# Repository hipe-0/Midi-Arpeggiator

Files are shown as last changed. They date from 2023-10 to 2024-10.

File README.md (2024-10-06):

# Midi-Arpeggiator: A Creative Tool for Musicians of All Levels

Hi, I'm Hippolyte Mounier, and I'm learning Arduino and electronics. This fun project has been a great way to unlock my musical creativity. The Midi-Arpeggiator serves as both an arpeggiator and a composition tool, helping me quickly express ideas even though I'm not a professional composer or pianist. Designed for use with DAW software like Ableton Live, FL Studio, and Reason, this plug-and-play device connects via USB to your desktop, offering a seamless experience. Check out the demo and see how this little Arduino project turned out more professional and robust than I ever expected—after just one week of development!

Demo here on Youtube https://www.youtube.com/watch?v=DeB5YvRfC6c

Photo of the Full Assembly:

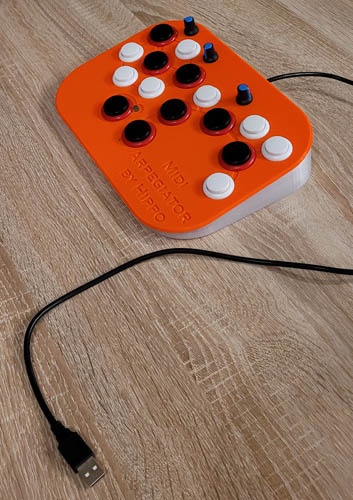
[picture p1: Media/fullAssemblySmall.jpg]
full assembly


Full schematic of the main panel: May look complex at first :-) but it's fool proof. My 10 years old daughter can play it! In theory you should use the big buttons more often than the small ones.

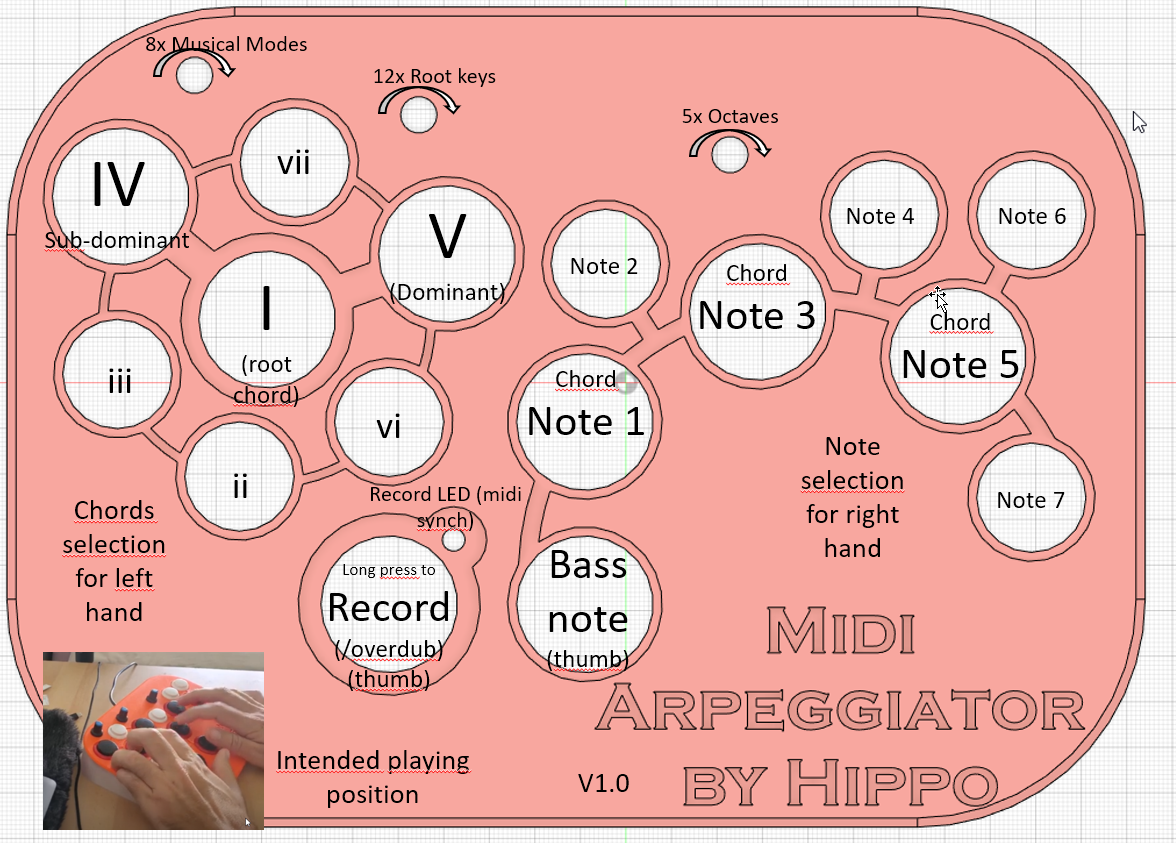
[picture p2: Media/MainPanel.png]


# Features 
+ USB midi controler
+ Original design
+ No reference to existing devices
+ Inspiration from software midi VST like Instachord, Melodicflow, Nora, Chtullu or Captain Chord.
+ 3D Made with Fusion 360. (files on thingiverse, see link below)
+ The body is 3D printed in PETG plastic, in 2 pieces : orange face (6h printing time) and translucent walls (3h printing time) glued together. A plug on the back secures the usb cable. (30 min printing time, in 2 parts)
+ Arcade machine buttons

# Usage tricks
7 buttons on left hand are presets for the chords I, II, III, IV, V, VI and VII of the mode and the root key (choosen via potentiometer below)
+  Pressing a chord button twice inverts the chord (minor gets major and major gets minor)
+  Pressing a chord 3 times pushes all notes +1 semitone, to reach out-of-harmony chords and accidentals

8 buttons for individual notes 1-7 in a key, similar to a piano white keys for C major
  + Inclusive a bass note for the right thumb, 1 octave down

A single record button. Performing :
  1. record (press continuously, it plays a loop immediately after button release), 
  2. play (short press), 
  3. overdub (press continuously while playing) 
  4. and stop (short press) 

# Potentiometer action

3x potentiometers for (8x)Mode, (12x)Root Keys and (5x)Octave

8x Music modes I choose are 
  1. Major
  2. Minor harmonic
  3. Minor melodic
  4. Minor natural (eolian)
  5. Dorian (celtic)
  6. Mixolydian (folk blues)
  7. Phrygian (metal)
  8. Phrygian Dominant (metal)

12x Root Keys I choose are 
+ in order of fiths starting with C, then G, D, A, E, B, F#, ...
+ Goal: being in fifths you can apply most useful tonal changes easily    

5x Octaves I choose are 
    -2, -1, 0, +1, +2

+ Recording led : green
+ The "brain" of the system is an Arduino micro, using midiusb library
+ Coding in C++ by me
+ I used a prototype board and soldered only some basic resistors and the wires.
+ Midi synchronisation as slave. 
+ Midi Velocity is fixed value (100) only
+ Midi Chanel 1 only
+ Latency is in my opinion negligible. At least on my Focusrite scarlett solo ASIO sound card. Some Latency can be seen on midi note editor.

It took me roughly about 12 h to build the prototype from start to finish. (I'm learning !)

# Shematic

2024-09-23 sketch Arpegiator v1 01_bb

2024-09-23 sketch Arpegiator v1 01_schéma

Arduino pins:
+ pin A0 connects to mode pot
+ pin A1 connects to Root pot
+ pin A2 connects to octave pot
+ pin A3 connects to chord buttons voltage read with Resistors in parallel for each button to differentiate voltages + 1 single 1K resitor in serie + 1 x 0.22uF capacitor in parallel for smooting the values, optional
+  button for chord I is connected directly with no resistor
+  button for chord II is in serie with 100 Ohm resistor
+  button for chord III is in serie with 320 Ohm resistor
+  button for chord IV is in serie with 560 Ohm resistor
+  button for chord V is in serie with 1K Ohm resistor
+  button for chord VI is in serie with 2.2K Ohm resistor
+  button for chord VII is in serie with 10K Ohm resistor

All note buttons are connected to GND

all pots connected to pin AREF and GND
+ pin 2 is connected to button note 1 
+ pin 3 is connected to button note 2
+ pin 4 is connected to button note 3
+ pin 5 is connected to button note 4
+ pin 6 is connected to button note 5
+ pin 7 is connected to button note 6
+ pin 8 is connected to button note 7
+ pin 10 is connected to LED in serie with resistor (probably 1K)
+ pin 11 is connected to button "bass" note
+ pin 12 in connected to record button

Dimensions: roughly 250 x 185 x 65

# Bill of materials:
+ Arduino Micro
+ 1m USB cable that connects USB A to USB micro
+ 8 large arcade buttons
+ 8 small arcade buttons
+ wire
+ 0.22 uF capacitor
+ 6x resistors R = 100, 320, 560, 1K, 2.2K and 10K
+ 1x resistor for the led R= 1K
+ PETG filament for 3D printer (PLA should do fine too)
+ 3D printer with heated bed and large >=250 cm print area
+ super glue, to bond the plate and the side wall
+ prototype board 70x90
+ 2x M3 screws
+ 3 potentiometers 10K
+ soldering iron

# Reddit thread

https://www.reddit.com/r/ArduinoProjects/comments/171mva3/new_arduino_based_midi_arpeggiator_3d_printed/

# 3D models

https://www.thingiverse.com/thing:6257589

# License:
CC BY-NC, see https://creativecommons.org/licenses/by-nc/4.0/
This license enables reusers to distribute, remix, adapt, and build upon the material in any medium or format for noncommercial purposes only, and only so long as attribution is given to the creator. CC BY-NC includes the following elements:

 BY: credit must be given to the creator.
 NC: Only noncommercial uses of the work are permitted.

Hippolyte

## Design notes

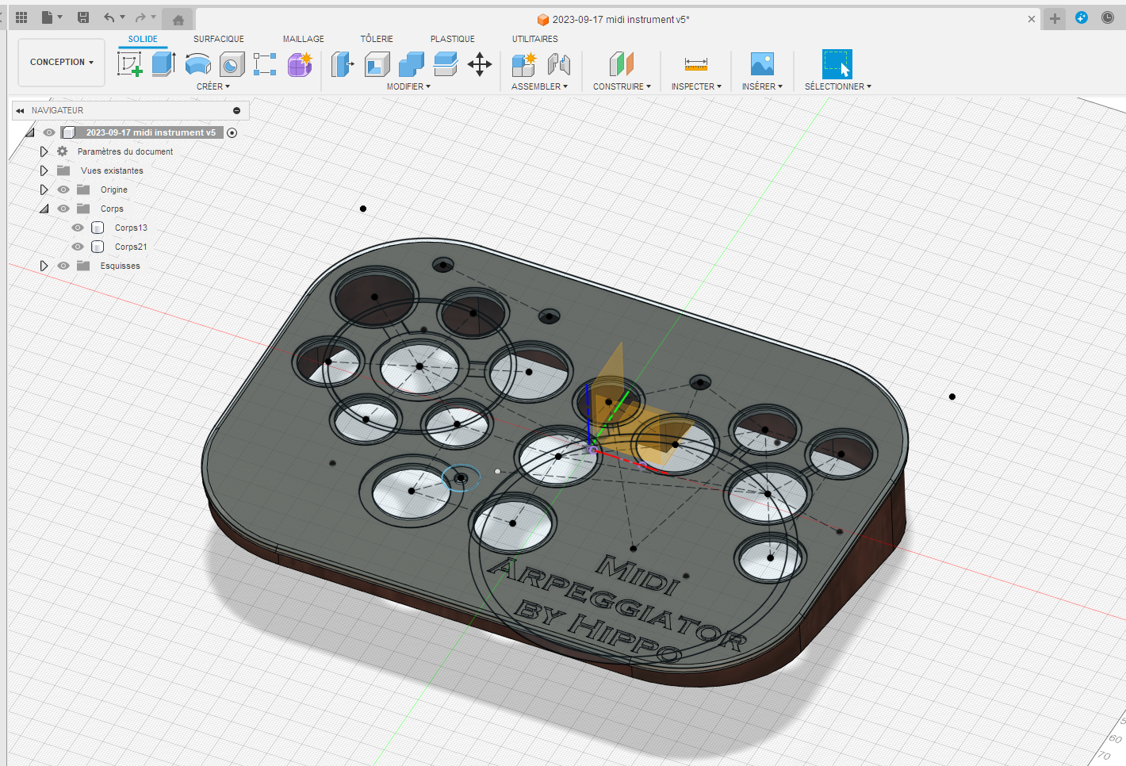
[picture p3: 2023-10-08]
Media/fusion360.png

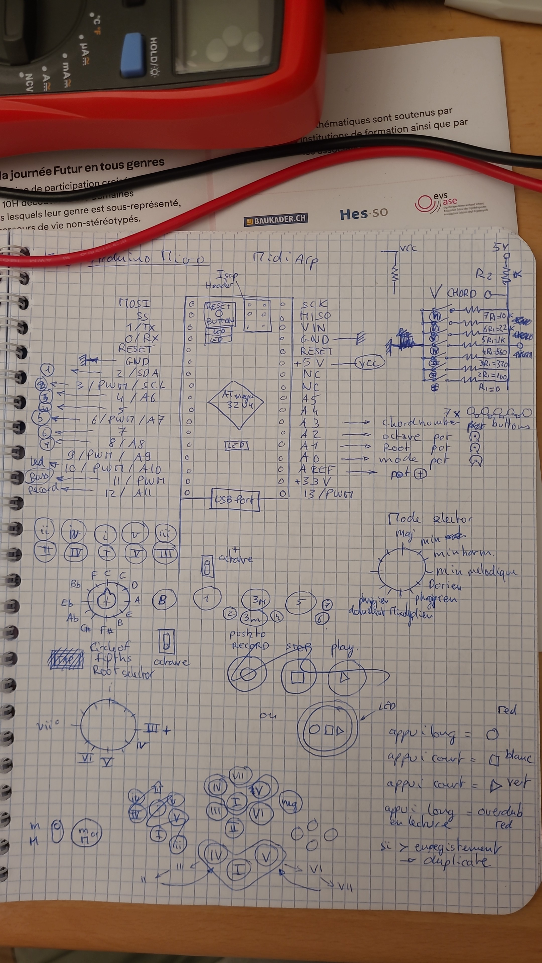
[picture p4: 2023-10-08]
Media/shema.jpeg

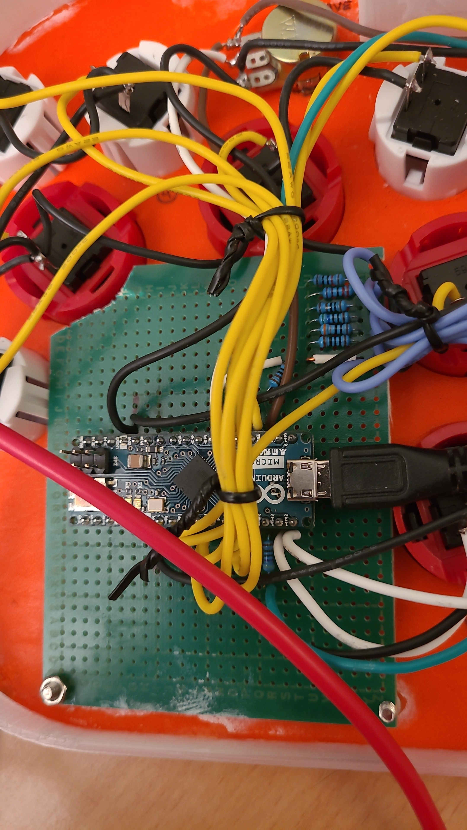
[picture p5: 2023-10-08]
Media/zoom on the prototype board.jpeg

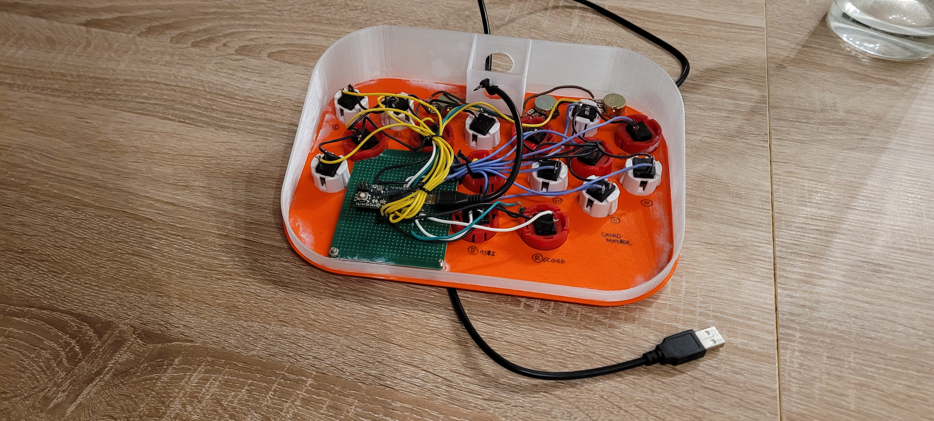
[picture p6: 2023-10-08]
Media/complete project.jpg

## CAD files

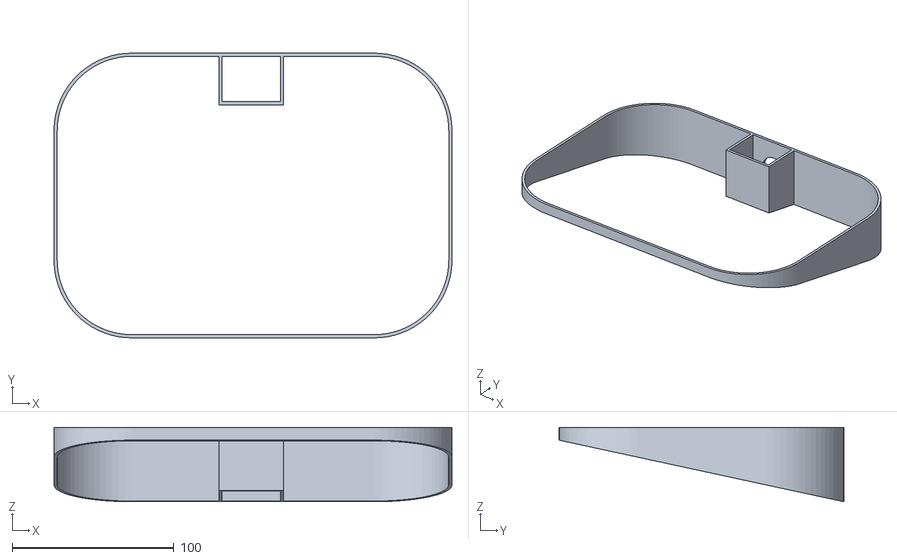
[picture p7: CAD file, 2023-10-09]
3DPrinting/sides.stl
246.0 x 176.0 x 46.0

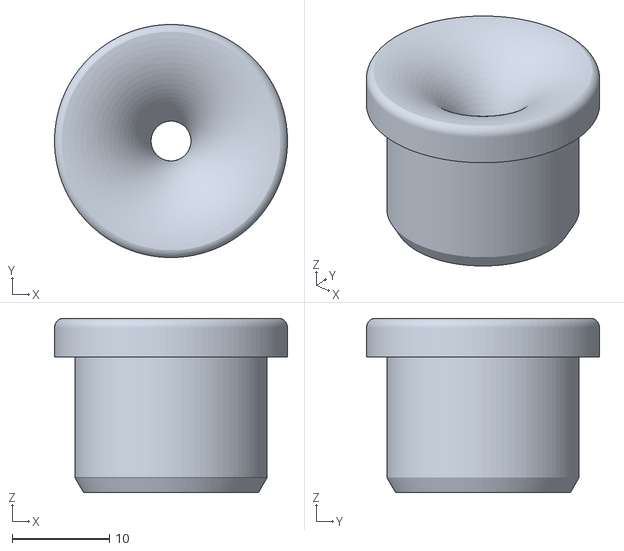
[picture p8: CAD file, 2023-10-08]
3DPrinting/plug2parts.stl
24.0 x 24.0 x 18.0

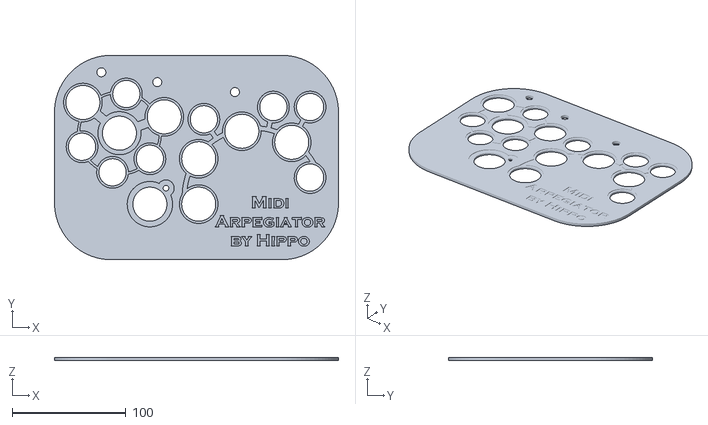
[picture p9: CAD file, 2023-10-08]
3DPrinting/Plate.stl
250.0 x 180.0 x 3.00

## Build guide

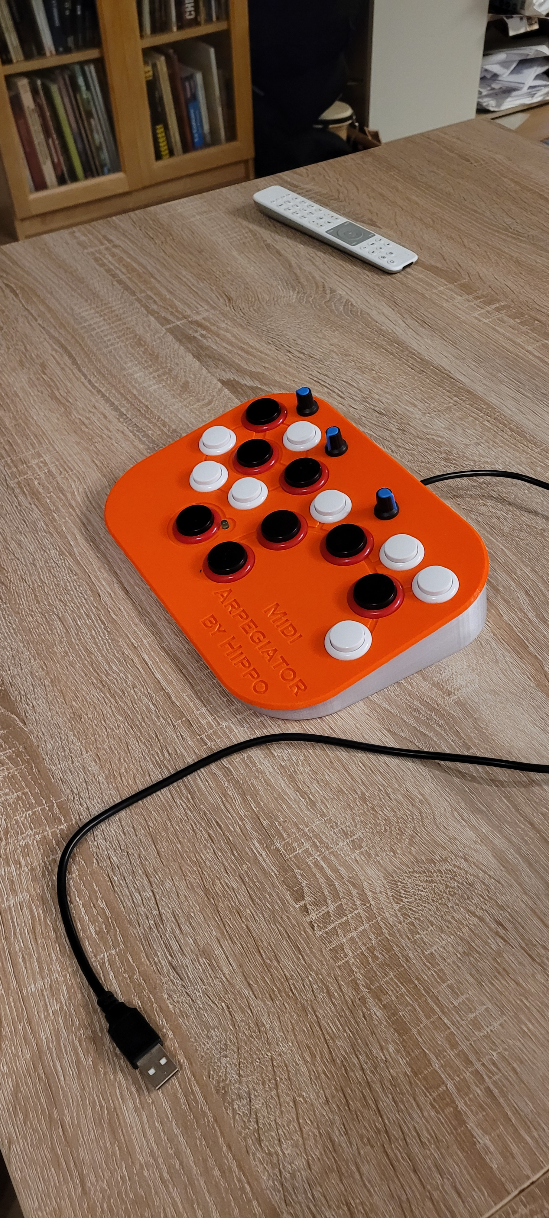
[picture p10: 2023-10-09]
Media/fullassembly.jpg

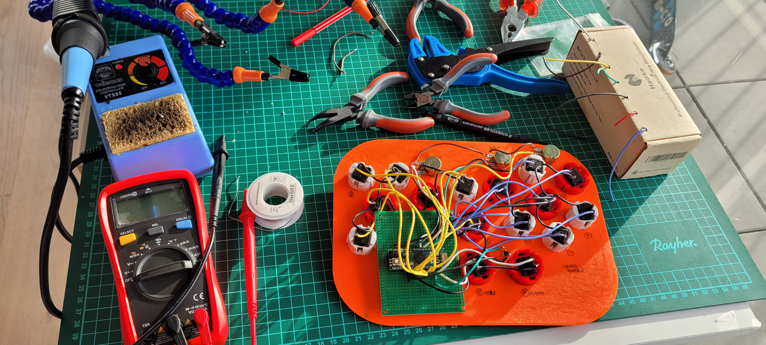
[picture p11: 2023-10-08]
Media/Assembly and testing with tools.jpg

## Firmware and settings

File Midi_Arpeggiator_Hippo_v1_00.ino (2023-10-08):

/*

   Midi Arpeggiator USB device

   Created: 2023-09-17
   Target device: Arduino Micro

   Author: Hippolyte Mounier


*/

#define NODEBUG

#include "debug.h"
#include "Led.h"
#include "Midi.h"
#include "ArpeggiatorMachine.h"
#include "RecordButtonManager.h"
#include "RecordManager.h"
#include "SynchManager.h"

ButtonManager        buttons;
PotentiometerManager pots;
Midi                 midi;
RecordButtonManager  recordButton;
RecordManager        record;
ArpeggiatorMachine   arp;
SynchManager         sync;

void setup() 
{
  Serial.begin(115200);
  DEBUGTXT("Setup was started")
  
  arp.initMidiOut      (midi);
  record.initPresses   (&buttons);
  record.initArpPointer(&arp);

  recordButton.turnOnLedManually(); delay(100);
}


void loop() 
{
  // Read hardware
  buttons.readAll();
  pots.readPotentiometers();
  midi.readMidiSynch();
  int s = midi.getSynchSignals();

  sync.setSynchValue(s);
  sync.setRecordPlayHeadMs(record.computePlayHeadMs());
  sync.compute();
  
  long u = sync.getUnSyncMs();  
  if (recordButton.isPlayingMusic()) record.shiftPlayHeadByMs(u);

  // manage hardware
  arp.setChordMode      ( pots.getChordMode()     );
  arp.setChordRootNote  ( pots.getChordRootNote() );
  arp.setChordOctave    ( pots.getChordOctave()   );
  arp.setChordNumber    ( pots.getChordNumber()   );
  arp.setChordAlternate ( pots.getExtraChordPress() );

  changeReadOrRecordStates();

  playAndRecordNotesFromButtons();

  if (s == 1) recordButton.turnOnLedManually();
  
  if ( recordButton.isPlayingMusic()) record.playRecordedNotes();
}


void changeReadOrRecordStates()
{
  int s = midi.getSynchSignals();
  recordButton.setSynch( s==0 || s==1 );
  recordButton.manageRecordButton();
  int state     = recordButton.getState();
  int prevState = recordButton.getPreviousState();

  if( state != prevState ) // change of state ?
  {
    switch( state )
    {
      case RECORD_RECORDING_OR_PLAY:     
        record.startRecording();
        sync.startRecordTimer();
        break;
      case RECORD_OVERDUB_OR_STOP:       
        record.startOverdubing();
        break;
      case RECORD_PLAY:
        if (prevState==RECORD_RECORDING) 
        {
          record.storeRecording();
          sync.storeRecordLength();
          record.startPlaying();
        }
        
        if (prevState==RECORD_OVERDUB) 
          record.storeOverdubing(); 

        if (prevState==RECORD_RECORDING_OR_PLAY || prevState==RECORD_OVERDUB_OR_STOP) 
          record.cancelOnGoingRecording();

        break;
      case RECORD_STOP:                  
        midi.killAllNotes(); 
        
        if (prevState==RECORD_RECORDING_OR_PLAY || prevState==RECORD_OVERDUB_OR_STOP) 
          record.cancelOnGoingRecording();

        record.stop();
        sync.stop();
        break;
    }
  }

}

int initialButtonPressOctave[8];

void playAndRecordNotesFromButtons()
{
  for (int i = 0; i < buttons.nbButtons(); i++)
  {
    if ( buttons.hasChanged(i) )
    {
      int octave = arp.getChordOctave();
      if(buttons.isPressed(i))
        initialButtonPressOctave[i] = octave;
      else
        octave = initialButtonPressOctave[i];
      
      //DEBUGVAL("playAndRecordNotesFromButtons octave = ", octave)
        
      //DEBUGVAL2("playAndRecordNotesFromButtons i = ",  i, " has changed ",  buttons.isPressed(i) )

      arp.playNoteMidi(i, arp.computePitch(i, octave), buttons.isPressed(i), octave);

      if(recordButton.isRecordingOrOverdub())
        record.recordNoteTemp(buttons.isPressed(i), i, octave);
    }
  }
}

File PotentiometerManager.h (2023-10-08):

// PIN numbers as soldered on the Arduino micro board
// Analog pins
const int POT_MODE_PIN          = 0;  // analog A0 input
const int POT_ROOT_NOTE_PIN     = 1;  // analog A1 input
const int POT_OCTAVE_PIN        = 2;  // analog A2 input
const int POT_CHORD_NUMBER_PIN  = 3;  // analog A3 input, actually not a pot, but provide same voltage as a pot
const int VALUE_STABILIZER      = 2; // filters chaotic values
const int SEMITONES_PER_OCTAVE  = 12;

#define MODE_COUNT              8
#define OCTAVE_COUNT            5


class PotentiometerManager
{
	private:
	int currentPots[4]; // store  state of all pots
	
	// store  chord state
	int chordMode_;
	int chordRootNote_;
	int chordOctave_;
  int chordNumber_;
  int transientChordNumber_;
  long transientTime_;
  bool isTransient_;
  int extraPresses_;
 
	public:
	PotentiometerManager() { chordNumber_=1;transientChordNumber_=1;extraPresses_=0; }
	
	void readPotentiometers()
	{
	  for(int i = 0; i<4 ; i++)
	  {
      int val = analogRead(i);

      if( abs(val - currentPots[i]) >= VALUE_STABILIZER )  // only changes of more that 2 points are recorded to avoid glitches
        currentPots[i] = val;
	  }
	  
	  chordMode_     = (int) (mapfloat(currentPots[ POT_MODE_PIN      ], 0, 1023, 0, MODE_COUNT - 1 ));
	  chordRootNote_ = (int) (mapfloat(currentPots[ POT_ROOT_NOTE_PIN ], 0, 1023, 0, SEMITONES_PER_OCTAVE - 1));
	  chordOctave_   = (int) (mapfloat(currentPots[ POT_OCTAVE_PIN    ], 0, 1023, 0, OCTAVE_COUNT - 1)) ;

    computeChordButtons_();
  }


	long mapfloat(long x, long in_min, long in_max, long out_min, long out_max)
	{
	  return round( (x - in_min) * (out_max - out_min) / (float) (in_max - in_min) + out_min );
	}
	
	int getChordMode()        { return chordMode_;     }
	int getChordRootNote()    { return chordRootNote_; }
	int getChordOctave()      { return chordOctave_;   }
	int getChordNumber()      { return chordNumber_;   }
  int getExtraChordPress()  { return extraPresses_;  } 

private:
	void computeChordButtons_()
  {
    int transientOld = transientChordNumber_;

    #define CHORD_TRANSIENT_DURATION 25
    #define NO_PRESS_NUMBER 8
//    #define DEAD_ZONE 20
    
    int potLevels[] = { 0, 50, 120, 330, 440, 610, 750, 970, 1023 };

	  int val = currentPots[POT_CHORD_NUMBER_PIN];
    for(int i=1 ; i < 9 ; i++)
      if ( val >= potLevels[i-1]  &&  val <= potLevels[i] ) 
        transientChordNumber_ = i;

    long d = millis()-transientTime_;
    /*
    Serial.print("transientChordNumber_ = ");
    Serial.print(transientChordNumber_);
    Serial.print("  chordNumber_ = ");
    Serial.print(chordNumber_);
    Serial.print("  val = ");
    Serial.println(val);*/

    if (transientOld != transientChordNumber_)
    {  
      transientTime_ = millis();
      isTransient_ = true;
    }
    else
      if(d > CHORD_TRANSIENT_DURATION && isTransient_ ) 
      {
        isTransient_ = false;
        if(transientChordNumber_!= NO_PRESS_NUMBER) 
        {
          if(chordNumber_ == transientChordNumber_)
          {
            extraPresses_++;
          }
          else
          {
            chordNumber_ = transientChordNumber_;
            isTransient_ = false;
            extraPresses_ = 0;
          }

          
          if(extraPresses_ > 0)
          {
            Serial.print("Alternate chord ");
            Serial.println(extraPresses_);
          }
          else
            Serial.println("Standard chord");
          
        }
      }

/*
    { // serial plotter for 
      Serial.print("-10,");
      Serial.print(val);
      Serial.println(",1030");
    }*/

  }

};

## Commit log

2023-10-08 Added all 3D models needed for 3D printing
    3x files, top part, side parts and a plug to secure the usb cable
    [2023-09-17 midi instrument v2.stl, 2023-09-17 midi instrument v3.stl, bouchon2 v1.stl]
2023-10-08 Some pictures of the assembly and shema
2023-10-09 tidy up some files
    [2023-09-17 midi instrument v3.stl, Plate.stl, plug2parts.stl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]
